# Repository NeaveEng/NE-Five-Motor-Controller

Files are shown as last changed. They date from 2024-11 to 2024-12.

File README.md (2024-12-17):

NE-Five Motor Driver
==

This is the PCB that controls the wheels and linear actuator on NE-Five, it's a work in progress and used entirely at your own risk. 

Highlights
==

It uses a Pi Pico at its core with four IFX9201SG motor controllers, it has one servo header that includes an analogue feedback pin to control a linear actuator.

Thanks!
==
Many thanks to Mark Mellors, Phillip Skippy McGaw, and Robert Karpinski for incredibly useful feedback!

# automatic image generation
### Images
top
bottom

Using [this github action](https://github.com/linalinn/kicad-render)

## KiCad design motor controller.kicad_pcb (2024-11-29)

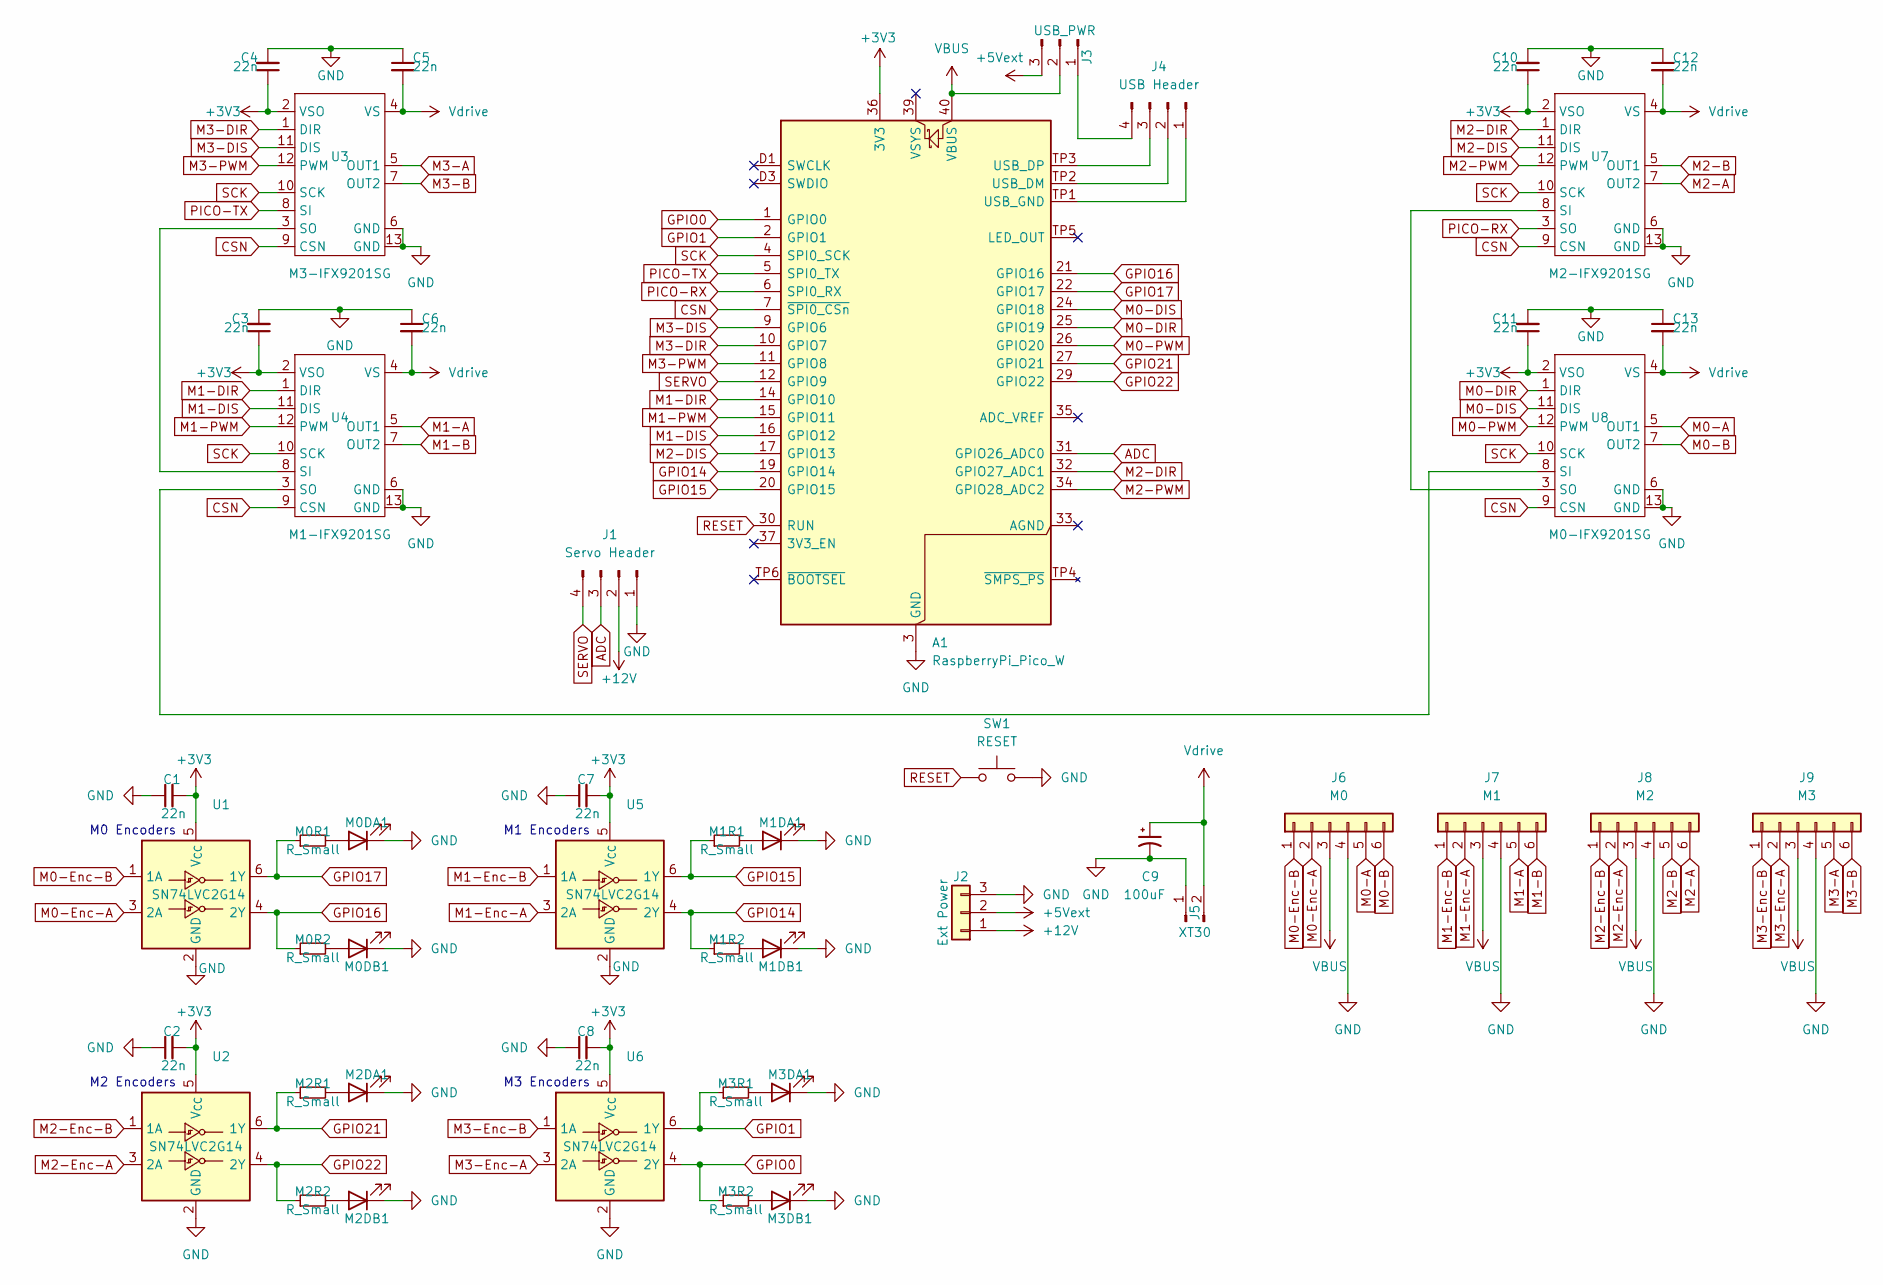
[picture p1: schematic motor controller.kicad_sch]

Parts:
A1: RaspberryPi_Pico_W; RaspberryPi_Pico_W_SMD
C1, C2, C3, C4, C5, C6, C7, C8, C10, C11, C12, C13: 22n; C_1206_3216Metric
C9: 100uF; CP_Radial_D6.3mm_P2.50mm
J1: Servo Header; JST_XH_B4B-XH-A_1x04_P2.50mm_Vertical
J2: Ext Power; JST_XH_B3B-XH-A_1x03_P2.50mm_Vertical
J3: USB_PWR; PinHeader_1x03_P2.54mm_Vertical
J4: USB Header; JST_XH_B4B-XH-A_1x04_P2.50mm_Vertical
J5: XT30; AMASS_XT30PW-M_1x02_P2.50mm_Horizontal
J6: M0; JST_XH_B6B-XH-A_1x06_P2.50mm_Vertical
J7: M1; JST_XH_B6B-XH-A_1x06_P2.50mm_Vertical
J8: M2; JST_XH_B6B-XH-A_1x06_P2.50mm_Vertical
J9: M3; JST_XH_B6B-XH-A_1x06_P2.50mm_Vertical
M0DA1, M0DB1, M1DA1, M1DB1, M2DA1, M2DB1, M3DA1, M3DB1: LED; LED_0805_2012Metric
M0R1, M0R2, M1R1, M1R2, M2R1, M2R2, M3R1, M3R2: R_Small; R_0805_2012Metric
SW1: RESET; SW_Push_1P1T_NO_CK_KMR2
U1, U2, U5, U6: SN74LVC2G14; SOT-23-6
U3: M3-IFX9201SG; PG_DSO_12_17
U4: M1-IFX9201SG; PG_DSO_12_17
U7: M2-IFX9201SG; PG_DSO_12_17
U8: M0-IFX9201SG; PG_DSO_12_17

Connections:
+3V3: A1.36 (3V3), C1.2, C2.2, C3.1, C4.1, C7.2, C8.2, C10.1, C11.1, U1.5 (V_{CC}), U2.5 (V_{CC}), U3.2 (VSO), U4.2 (VSO), U5.5 (V_{CC}), U6.5 (V_{CC}), U7.2 (VSO), U8.2 (VSO)
+5Vext: J2.2 (5v), J3.3
+12V: J1.2, J2.1 (GND)
ADC: A1.31 (GPIO26_ADC0), J1.3
CSN: A1.7 (~SPI0_CSn), U3.9 (CSN), U4.9 (CSN), U7.9 (CSN), U8.9 (CSN)
GND: A1.3 (GND), A1.8 (GND), A1.13 (GND), A1.18 (GND), A1.23 (GND), A1.28 (GND), A1.38 (GND), A1.D2 (GND), C1.1, C2.1, C3.2, C4.2, C5.1, C6.1, C7.1, C8.1, C9.2, C10.2, C11.2, C12.1, C13.1, J1.1, J2.3 (12v), J5.1 (-), J6.4, J7.4, J8.4, J9.4, M0DA1.1 (K), M0DB1.1 (K), M1DA1.1 (K), M1DB1.1 (K), M2DA1.1 (K), M2DB1.1 (K), M3DA1.1 (K), M3DB1.1 (K), SW1.2, U1.2 (GND), U2.2 (GND), U3.6 (GND), U3.13 (GND), U4.6 (GND), U4.13 (GND), U5.2 (GND), U6.2 (GND), U7.6 (GND), U7.13 (GND), U8.6 (GND), U8.13 (GND)
GPIO0: A1.1 (GPIO0), M3R2.1, U6.4 (2Y)
GPIO1: A1.2 (GPIO1), M3R1.1, U6.6 (1Y)
GPIO14: A1.19 (GPIO14), M1R2.1, U5.4 (2Y)
GPIO15: A1.20 (GPIO15), M1R1.1, U5.6 (1Y)
GPIO16: A1.21 (GPIO16), M0R2.1, U1.4 (2Y)
GPIO17: A1.22 (GPIO17), M0R1.1, U1.6 (1Y)
GPIO21: A1.27 (GPIO21), M2R1.1, U2.6 (1Y)
GPIO22: A1.29 (GPIO22), M2R2.1, U2.4 (2Y)
M0-A: J6.5, U8.5 (OUT1)
M0-B: J6.6, U8.7 (OUT2)
M0-DIR: A1.25 (GPIO19), U8.1 (DIR)
M0-DIS: A1.24 (GPIO18), U8.11 (DIS)
M0-Enc-A: J6.2, U1.3 (2A)
M0-Enc-B: J6.1, U1.1 (1A)
M0-PWM: A1.26 (GPIO20), U8.12 (PWM)
M1-A: J7.5, U4.5 (OUT1)
M1-B: J7.6, U4.7 (OUT2)
M1-DIR: A1.14 (GPIO10), U4.1 (DIR)
M1-DIS: A1.16 (GPIO12), U4.11 (DIS)
M1-Enc-A: J7.2, U5.3 (2A)
M1-Enc-B: J7.1, U5.1 (1A)
M1-PWM: A1.15 (GPIO11), U4.12 (PWM)
M2-A: J8.6, U7.7 (OUT2)
M2-B: J8.5, U7.5 (OUT1)
M2-DIR: A1.32 (GPIO27_ADC1), U7.1 (DIR)
M2-DIS: A1.17 (GPIO13), U7.11 (DIS)
M2-Enc-A: J8.2, U2.3 (2A)
M2-Enc-B: J8.1, U2.1 (1A)
M2-PWM: A1.34 (GPIO28_ADC2), U7.12 (PWM)
M3-A: J9.5, U3.5 (OUT1)
M3-B: J9.6, U3.7 (OUT2)
M3-DIR: A1.10 (GPIO7), U3.1 (DIR)
M3-DIS: A1.9 (GPIO6), U3.11 (DIS)
M3-Enc-A: J9.2, U6.3 (2A)
M3-Enc-B: J9.1, U6.1 (1A)
M3-PWM: A1.11 (GPIO8), U3.12 (PWM)
unnamed: A1.TP2 (USB_DM), J4.2
unnamed: A1.TP3 (USB_DP), J4.3
unnamed: A1.TP1 (USB_GND), J4.1
unnamed: J3.1, J4.4
unnamed: M0DA1.2 (A), M0R1.2
unnamed: M0DB1.2 (A), M0R2.2
unnamed: M1DA1.2 (A), M1R1.2
unnamed: M1DB1.2 (A), M1R2.2
unnamed: M2DA1.2 (A), M2R1.2
unnamed: M2DB1.2 (A), M2R2.2
unnamed: M3DA1.2 (A), M3R1.2
unnamed: M3DB1.2 (A), M3R2.2
unnamed: U3.3 (SO), U4.8 (SI)
unnamed: U4.3 (SO), U8.8 (SI)
unnamed: U7.8 (SI), U8.3 (SO)
PICO-RX: A1.6 (SPI0_RX), U7.3 (SO)
PICO-TX: A1.5 (SPI0_TX), U3.8 (SI)
RESET: A1.30 (RUN), SW1.1
SCK: A1.4 (SPI0_SCK), U3.10 (SCK), U4.10 (SCK), U7.10 (SCK), U8.10 (SCK)
SERVO: A1.12 (GPIO9), J1.4
VBUS: A1.40 (VBUS), J3.2, J6.3, J7.3, J8.3, J9.3
Vdrive: C5.2, C6.2, C9.1, C12.2, C13.2, J5.2 (+), U3.4 (VS), U4.4 (VS), U7.4 (VS), U8.4 (VS)

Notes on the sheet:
M3 Encoders
M1 Encoders
M2 Encoders
M0 Encoders

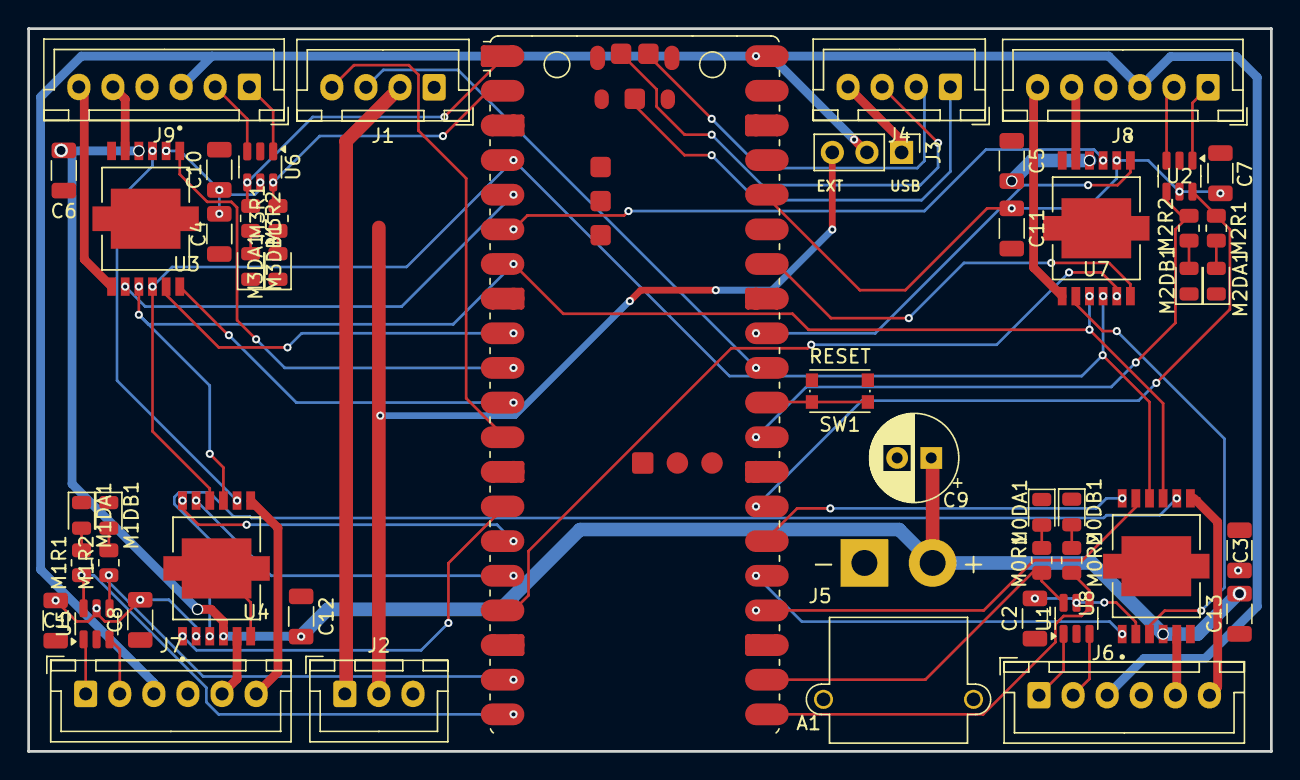
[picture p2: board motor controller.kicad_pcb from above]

Board: 2 copper layers, 91.1 x 53.0 mm, 48 parts (0 on the bottom side), 64 nets.

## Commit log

2024-11-27 initial checkin
    [motor controller.kicad_pcb, motor controller.kicad_sch]
2024-11-27 updated schematic and pcb
    [motor controller.kicad_pcb, motor controller.kicad_sch]
2024-11-27 changes suggested by Rob
    [motor controller.kicad_sch]
2024-11-27 fixed a short, started updating the PCB layout
    [motor controller.kicad_pcb, motor controller.kicad_sch]
2024-11-28 more tweaking
    [motor controller.kicad_pcb, motor controller.kicad_sch]
2024-11-28 switched to vertical plugs
    [motor controller.kicad_sch]
2024-11-29 trying again to get the PCB layout to work
    [motor controller.kicad_pcb, motor controller.kicad_sch]
2024-11-29 deleted the schematic pdf as it's out of date
